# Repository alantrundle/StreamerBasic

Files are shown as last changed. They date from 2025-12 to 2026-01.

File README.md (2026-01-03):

# ESP32 Audio Streaming & Playback Platform

An all-in-one **ESP32-based audio platform** providing HTTP streaming, on-device decoding, and multiple audio outputs with a full graphical UI.  
Designed for **ESP32-WROVER (8MB PSRAM)** and intended for use with a custom PCB (v1.1) or off-the-shelf modules.

---

## 📸 PCB – Prototype (v1.1)

<p align="center">
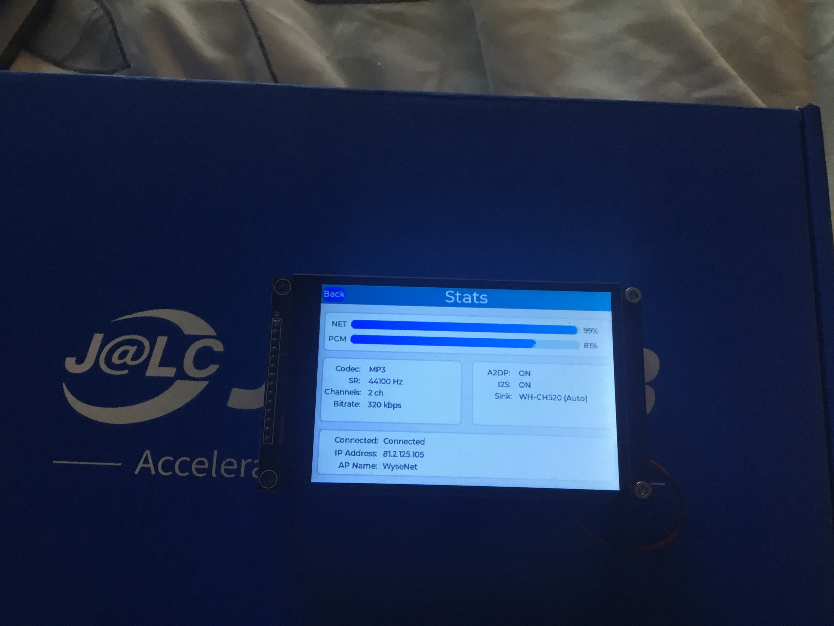
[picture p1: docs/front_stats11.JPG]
  
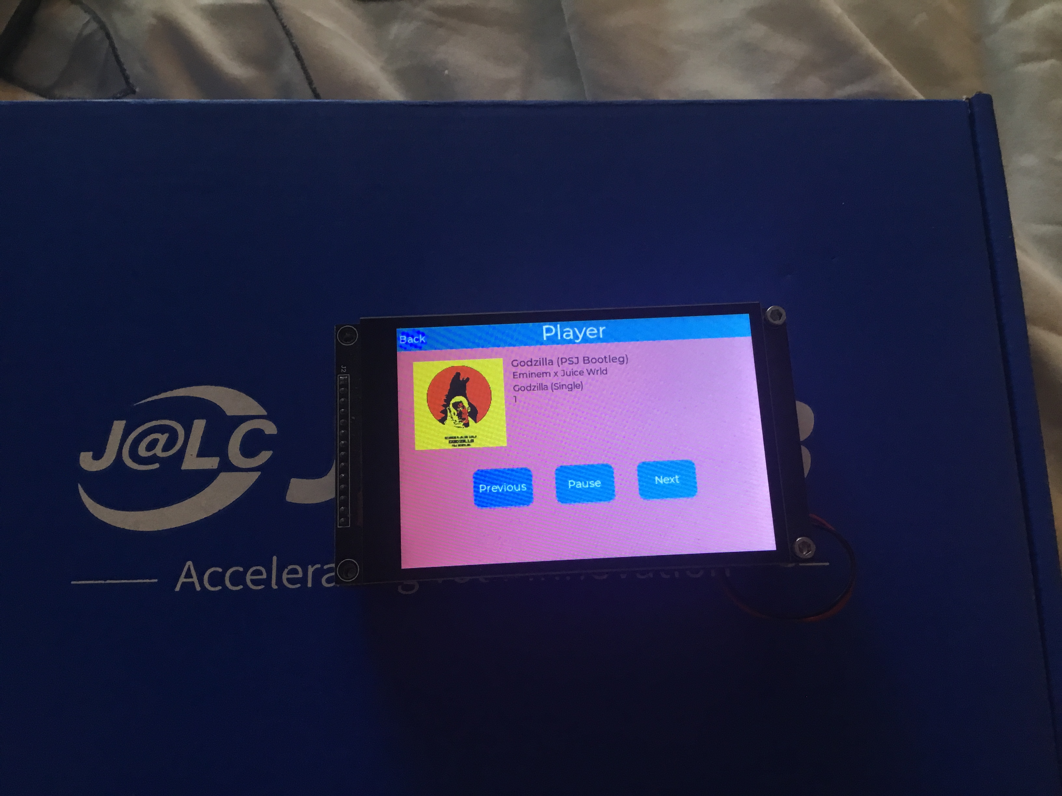
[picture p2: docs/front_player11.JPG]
  
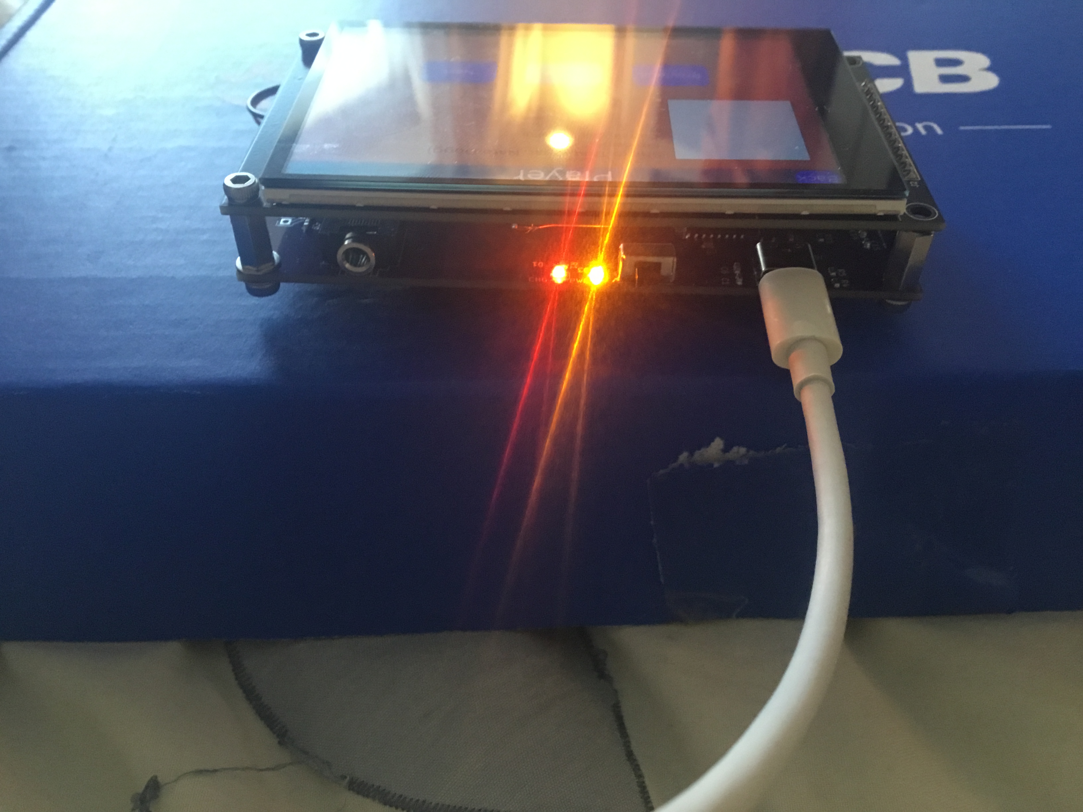
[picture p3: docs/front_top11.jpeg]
  
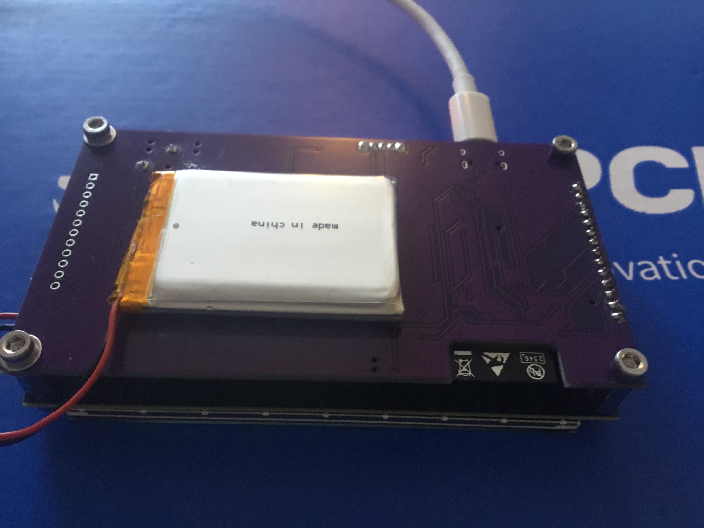
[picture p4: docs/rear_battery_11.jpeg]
  
</p>

**Left → Right:**  
Front view with LVGL UI • Angled top view • Rear view with Li-Po battery fitted

> ⚠️ **ESP32-WROVER with 8MB PSRAM is mandatory**  
> Bluetooth Classic (A2DP) and LVGL require PSRAM for stability.

---

## ✨ Key Features

- **Automatic MP3 & AAC codec detection** (header-level)
- **ID3v2 tag parsing** (title, artist, album & JPEG Album Art)
- **Bluetooth A2DP output**
  - Line-out & A2DP sinks supported
  - Automatic reconnect logic
- **I2S audio output**
  - Developed using PCM5102 DAC
- **Dual-reader PCM ring buffer**
  - Independent A2DP & I2S consumption
- **LVGL graphical UI**
  - Touch support
  - ST7796 demo included
- **Transport controls**
  - Play / Pause / Stop
  - Next / Previous track

---

## 🧠 Architecture Overview

- HTTP audio streaming
- On-device MP3 / AAC decoding
- Shared PCM buffer with independent read pointers
- Parallel output to:
  - Bluetooth A2DP
  - I2S DAC
- LVGL UI running primarily from PSRAM
- Designed around **FreeRTOS task separation** and buffer hysteresis

---

## ⚠️ Known Issues & Limitations

- **LVGL + Bluetooth + Wi-Fi are extremely DRAM-heavy**
  - LVGL buffers must reside mostly in PSRAM
  - Moving `lvbuf1` to DRAM can crash Wi-Fi + BT
- **Dual buffering in PSRAM is slow**
  - Trade-off required for system stability
- **Wi-Fi coexistence instability**
  - Occasional crashes under heavy load
- **ESP-IDF versions**
  - Rolled back to **ESP32 core v6.4.0** for stability
  - Newer versions attempt BT sleep → A2DP instability
- **Bluetooth**
  - Rare crashes due to DRAM exhaustion
  - Actively under investigation

---

## 🧪 Current Testing Status

- LVGL running partially in DRAM  
  - Single-buffer, 4-line configuration
- **24-hour soak test** currently in progress
- PCB **v1.1 production** underway

---

## 🛠 To-Do

- Plex Media Server integration
- General bug fixes & cleanup
- Ogg Vorbis support
- Improved AAC decoding
- LVGL dual buffering in DRAM (if feasible)

---

## ✅ Pros

- Stable during extended playback
- Robust codec detection
- Clean separation of decode and output paths
- Scales well with PSRAM availability

---

## 📦 Recommended Development Kit (Without PCB)

### ESP32 Module
**ESP32-WROVER (8MB PSRAM + TF Card)**
- https://www.aliexpress.com/item/32879370278.html

### Display
**4″ TFT Capacitive Touch Display**  
(Required for PCB v1.1 – LVGL)
- https://www.aliexpress.com/item/1005006698127763.html

### Audio DAC
**PCM5102 I2S DAC**
- Stereo RCA + headphone/line-out
- https://www.aliexpress.com/item/1005005352684938.html

---

## 📄 License

**Project status:** Active Development  

**License:**  
Free for **personal, educational, and hobbyist use**.

**Commercial use is not permitted without explicit written permission from the author.**  
This includes (but is not limited to) use in commercial products, services, or redistributed hardware.

If you wish to use this project commercially, please contact the author via GitHub.

---

## 🙌 Acknowledgements

- ESP32 Arduino Core
- LVGL Graphics Library
- Helix Audio Codecs

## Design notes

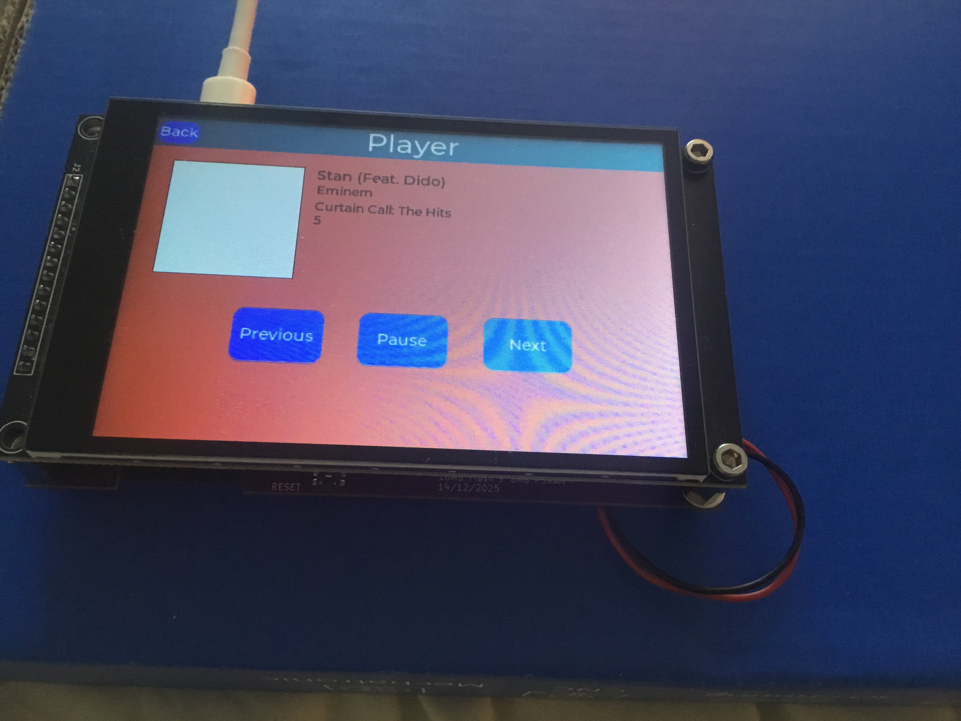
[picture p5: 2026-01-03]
docs/front11.jpeg

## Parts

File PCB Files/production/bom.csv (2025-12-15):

Designator | Footprint | Quantity | Value | LCSC Part #
C1, C15, C18, C19, C2, C23, C25, C26, C5, C7, C9 | 0603 | 11 | 100nF | C14663
C14, C20, C22, C3, C4, C6, C8 | 0603 | 7 | 10uF | C19702
C16, C17 | 0603 | 2 | 2.2nF | C1604
C21, C24 | 0603 | 2 | 2.2uF | C23630
D1 | 0805 | 1 | Charge | C84256
D2 | D_SOD-123 | 1 | MBR0520 | C8598
D3 | 0805 | 1 | LED | C2296
H1, H2, H3, H4 | MountingHole_3.2mm_M3_ISO14580 | 4 | MountingHole
J2 | JST_ZH_S2B-ZR-SM4A-TF_1x02-1MP_P1.50mm_Horizontal | 1 | Lipo 1S
J3 | PinSocket_1x14_P2.54mm_Vertical | 1 | Display
J4 | Jack_3.5mm_CUI_SJ1-3523N_Horizontal | 1 | AudioJack3 | C20182914
J5 | PinSocket_1x12_P2.54mm_Vertical | 1 | expansion
J6 | USB_C_Receptacle_HRO_TYPE-C-31-M-12 | 1 | USB_C_Receptacle_USB2.0_14P | C165948
Q1, Q2 | SOT-23 | 2 | AO3400A | C20917
Q3 | SOT-23 | 1 | AO3401A | C15127
R1, R3 | 0603 | 2 | 1k | C21190
R10 | 0603 | 1 | 220R | C22962
R11, R8 | 0603 | 2 | 10K | C25804
R2 | 0603 | 1 | 2.2k | C4190
R4, R5 | 0603 | 2 | 5k1 | C23186
R6, R7 | 0603 | 2 | 470R | C23179
R9 | 0603 | 1 | 100K | C25803
SW1 | SW_Slide_SPDT_Angled_CK_OS102011MA1Q | 1 | SW_SPST | C226259
SW2 | SW_SPST_EVQP7C | 1 | RESET | C388883
U1 | ESP32-WROVER-E | 1 | ESP32-WROVER-E | C701342
U2 | SOIC-16_3.9x9.9mm_P1.27mm | 1 | CH340C | C84681
U3 | SOT-23-5 | 1 | MCP73831-2-OT | C424093
U4 | SOT-23-5 | 1 | AP2112K-3.3 | C51118
U5 | TSSOP-20_4.4x6.5mm_P0.65mm | 1 | PCM5102A | C107671

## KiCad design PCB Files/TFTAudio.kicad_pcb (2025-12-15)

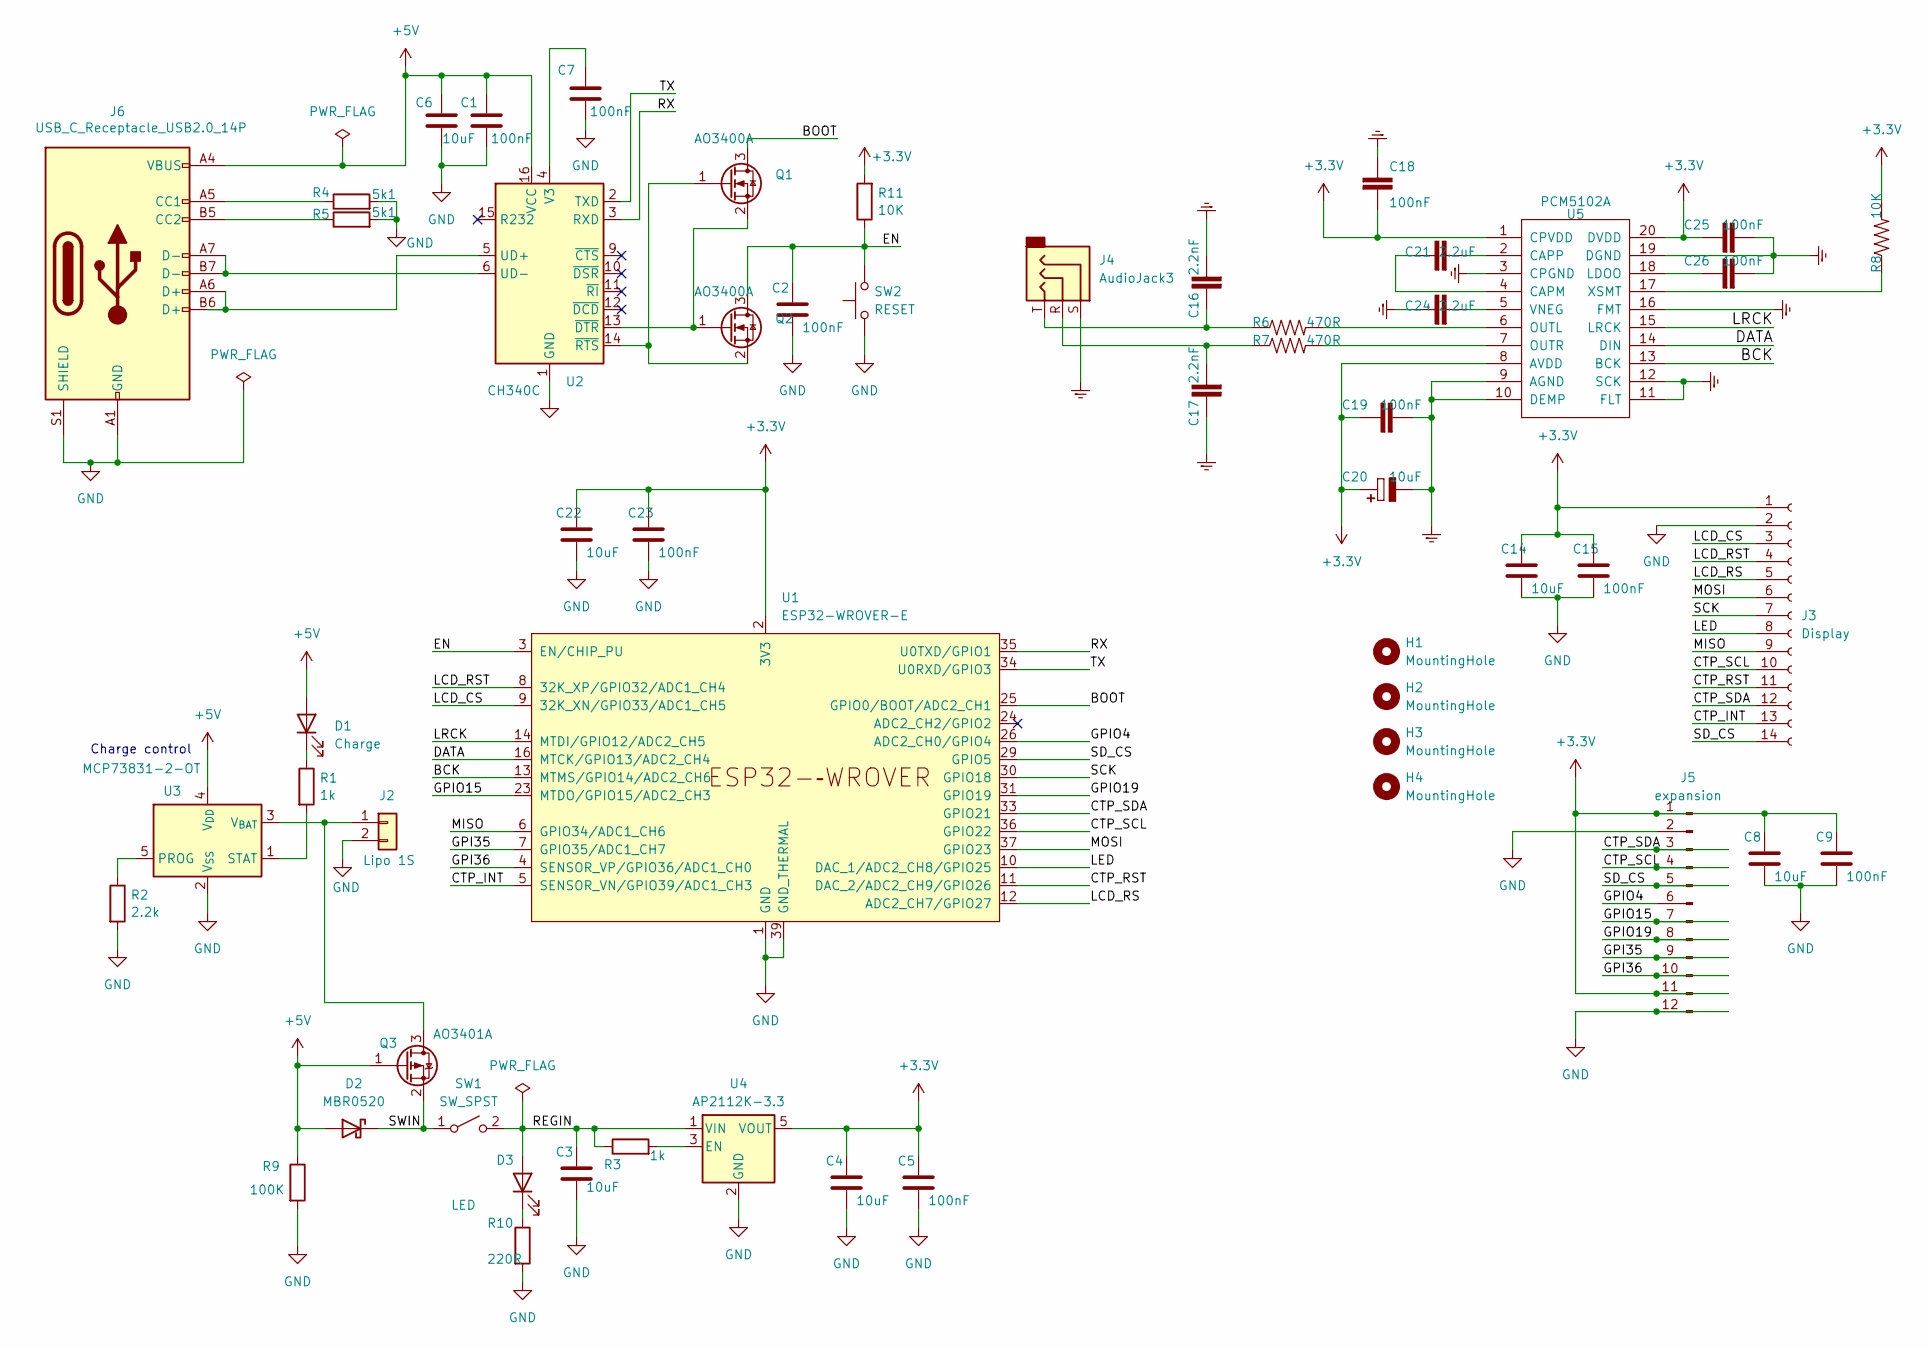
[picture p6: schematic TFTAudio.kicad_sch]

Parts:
C1, C2, C5, C7, C9, C15, C18, C19, C23, C25, C26: 100nF; C_0603_1608Metric; LCSC C14663
C3, C4, C6, C8, C14, C20, C22: 10uF; C_0603_1608Metric; LCSC C19702
C16, C17: 2.2nF; C_0603_1608Metric; LCSC C1604
C21, C24: 2.2uF; C_0603_1608Metric; LCSC C23630
D1: Charge; LED_0805_2012Metric; LCSC C84256
D2: MBR0520; D_SOD-123; LCSC C8598
D3: LED; LED_0805_2012Metric; LCSC C2296
H1, H2, H3, H4: MountingHole; MountingHole_3.2mm_M3_ISO14580
J2: Lipo 1S; JST_ZH_S2B-ZR-SM4A-TF_1x02-1MP_P1.50mm_Horizontal
J3: Display; PinSocket_1x14_P2.54mm_Vertical
J4: AudioJack3; Jack_3.5mm_CUI_SJ1-3523N_Horizontal; LCSC C20182914
J5: expansion; PinSocket_1x12_P2.54mm_Vertical
J6: USB_C_Receptacle_USB2.0_14P; USB_C_Receptacle_HRO_TYPE-C-31-M-12; LCSC C165948
Q1, Q2: AO3400A; SOT-23; LCSC C20917
Q3: AO3401A; Package_TO_SOT_SMD; LCSC C15127
R1, R3: 1k; R_0603_1608Metric; LCSC C21190
R2: 2.2k; R_0603_1608Metric; LCSC C4190
R4, R5: 5k1; R_0603_1608Metric; LCSC C23186
R6, R7: 470R; R_0603_1608Metric; LCSC C23179
R8, R11: 10K; R_0603_1608Metric; LCSC C25804
R9: 100K; R_0603_1608Metric; LCSC C25803
R10: 220R; R_0603_1608Metric; LCSC C22962
SW1: SW_SPST; SW_Slide_SPDT_Angled_CK_OS102011MA1Q; LCSC C226259
SW2: RESET; SW_SPST_EVQP7C; LCSC C388883
U1: ESP32-WROVER-E; LCSC C701342
U2: CH340C; SOIC-16_3.9x9.9mm_P1.27mm; LCSC C84681
U3: MCP73831-2-OT; SOT-23-5; LCSC C424093
U4: AP2112K-3.3; SOT-23-5; LCSC C51118
U5: PCM5102A; TSSOP-20_4.4x6.5mm_P0.65mm; LCSC C107671

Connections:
+3.3V: C4.1, C5.1, C8.1, C9.1, C14.1, C15.1, C18.2, C19.1, C20.1 (+), C22.1, C23.1, C25.1, J3.1, J5.1, J5.11, R8.2, R11.2, U1.2 (3V3), U4.5 (VOUT), U5.1 (CPVDD), U5.8 (AVDD), U5.20 (DVDD)
+5V: C1.1, C6.1, D1.2 (A), D2.2 (A), J6.A4 (VBUS), J6.A9 (VBUS), J6.B4 (VBUS), J6.B9 (VBUS), Q3.1 (G), R9.1, U2.16 (VCC), U3.4 (V_{DD})
/BCK: U1.13 (MTMS/GPIO14/ADC2_CH6), U5.13 (BCK)
/BOOT: Q1.3 (D), U1.25 (GPIO0/BOOT/ADC2_CH1)
/CTP_INT: J3.13, U1.5 (SENSOR_VN/GPIO39/ADC1_CH3)
/CTP_RST: J3.11, U1.11 (DAC_2/ADC2_CH9/GPIO26)
/CTP_SCL: J3.10, J5.4, U1.36 (GPIO22)
/CTP_SDA: J3.12, J5.3, U1.33 (GPIO21)
/DATA: U1.16 (MTCK/GPIO13/ADC2_CH4), U5.14 (DIN)
/EN: C2.1, Q2.3 (D), R11.1, SW2.2, U1.3 (EN/CHIP_PU)
/GPI35: J5.9, U1.7 (GPIO35/ADC1_CH7)
/GPI36: J5.10, U1.4 (SENSOR_VP/GPIO36/ADC1_CH0)
/GPIO4: J5.6, U1.26 (ADC2_CH0/GPIO4)
/GPIO15: J5.7, U1.23 (MTDO/GPIO15/ADC2_CH3)
/GPIO19: J5.8, U1.31 (GPIO19)
/LCD_CS: J3.3, U1.9 (32K_XN/GPIO33/ADC1_CH5)
/LCD_RS: J3.5, U1.12 (ADC2_CH7/GPIO27)
/LCD_RST: J3.4, U1.8 (32K_XP/GPIO32/ADC1_CH4)
/LED: J3.8, U1.10 (DAC_1/ADC2_CH8/GPIO25)
/LRCK: U1.14 (MTDI/GPIO12/ADC2_CH5), U5.15 (LRCK)
/MISO: J3.9, U1.6 (GPIO34/ADC1_CH6)
/MOSI: J3.6, U1.37 (GPIO23)
/REGIN: C3.1, D3.2 (A), R3.1, SW1.2 (B), U4.1 (VIN)
/RX: U1.35 (U0TXD/GPIO1), U2.3 (RXD)
/SCK: J3.7, U1.30 (GPIO18)
/SD_CS: J3.14, J5.5, U1.29 (GPIO5)
/SWIN: D2.1 (K), Q3.2 (S), SW1.1 (A)
/TX: U1.34 (U0RXD/GPIO3), U2.2 (TXD)
GND: C1.2, C2.2, C3.2, C4.2, C5.2, C6.2, C7.2, C8.2, C9.2, C14.2, C15.2, C16.2, C17.1, C18.1, C19.2, C20.2 (-), C22.2, C23.2, C24.1, C25.2, C26.2, J2.2, J3.2, J4.S, J5.2, J5.12, J6.A1 (GND), J6.A12 (GND), J6.B1 (GND), J6.B12 (GND), J6.S1 (SHIELD), R2.2, R4.2, R5.2, R9.2, R10.2, SW2.1, U1.1 (GND), U1.15 (GND), U1.38 (GND), U1.39 (GND_THERMAL), U2.1 (GND), U3.2 (V_{SS}), U4.2 (GND), U5.3 (CPGND), U5.9 (AGND), U5.10 (DEMP), U5.11 (FLT), U5.12 (SCK), U5.16 (FMT), U5.19 (DGND)
unnamed: C16.1, J4.T, R6.1
unnamed: C17.2, J4.R, R7.1
unnamed: D1.1 (K), R1.1
unnamed: D3.1 (K), R10.1
unnamed: J2.1, Q3.3 (D), U3.3 (V_{BAT})
unnamed: J6.A5 (CC1), R4.1
unnamed: J6.B5 (CC2), R5.1
unnamed: Q1.1 (G), Q2.2 (S), U2.14 (~RTS)
unnamed: Q1.2 (S), Q2.1 (G), U2.13 (~DTR)
unnamed: J6.A6 (D+), J6.B6 (D+), U2.5 (UD+)
unnamed: J6.A7 (D-), J6.B7 (D-), U2.6 (UD-)
unnamed: C7.1, U2.4 (V3)
unnamed: R2.1, U3.5 (PROG)
unnamed: R1.2, U3.1 (STAT)
unnamed: R3.2, U4.3 (EN)
unnamed: C21.1, U5.4 (CAPM)
unnamed: C21.2, U5.2 (CAPP)
unnamed: C26.1, U5.18 (LDOO)
unnamed: R6.2, U5.6 (OUTL)
unnamed: R7.2, U5.7 (OUTR)
unnamed: C24.2, U5.5 (VNEG)
unnamed: R8.1, U5.17 (XSMT)

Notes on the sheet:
Charge control

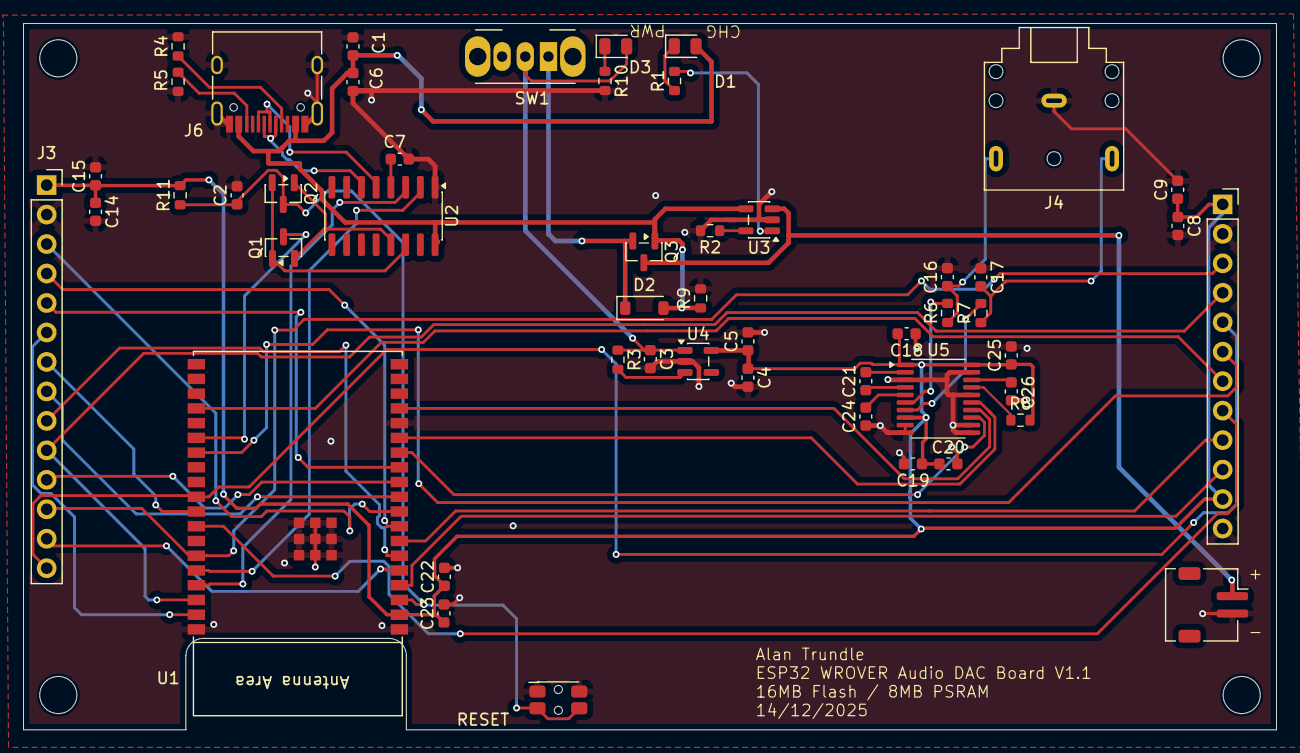
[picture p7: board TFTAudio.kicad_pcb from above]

Board: 2 copper layers, 108.0 x 60.9 mm, 55 parts (0 on the bottom side), 51 nets.

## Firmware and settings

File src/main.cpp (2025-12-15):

#include <Arduino.h>
#include <WiFi.h>
#include "esp_wifi.h"
#include "esp_system.h"

#include "Config.h"
#include "AudioCore.h"
#include "HttpStreamEngine.h"
#include "A2DPCore.h"

#include "LVGLCore.h"
#include "ui/ui.h"

#include "AudioPlayer.h"

#include "sdkconfig.h"

A2DPCore a2dp;


// ------------------------------------------------------------
// Wi-Fi helper
// ------------------------------------------------------------

static void connectWiFi() {
  Serial.printf("[WIFI] Connecting to %s\n", WIFI_SSID);

  WiFi.mode(WIFI_STA);
  WiFi.begin(WIFI_SSID, WIFI_PASS);

  uint32_t start = millis();
  while (WiFi.status() != WL_CONNECTED) {
    delay(250);
    Serial.print(".");
    if (millis() - start > 30000) {
      Serial.println("\n[WIFI] ❌ Connection timeout");
      return;
    }
  }



  Serial.printf("\n[WIFI] ✅ Connected, IP=%s\n",
                WiFi.localIP().toString().c_str());
}

#include <string.h>

void btScanCallback(int count,
                    const char* const* names,
                    const char* const* macs,
                    const int8_t* rssis)
{
    static bool connect = false;

    if (connect) return;

    for (int i = 0; i < count; i++) {

        if (!names[i]) continue;

        if (strcmp(names[i], "WH-CH520") == 0) {

            Serial.printf("Connecting to %s (%s, RSSI %d)\r\n",
                          names[i],
                          macs ? macs[i] : "??",
                          rssis ? rssis[i] : 0);

            a2dp.connect_by_index(i);
            connect = true;
            return;
        }
    }
}


void memUsage() {

size_t dma_free = heap_caps_get_largest_free_block(MALLOC_CAP_DMA | MALLOC_CAP_INTERNAL);
size_t int_free = heap_caps_get_free_size(MALLOC_CAP_INTERNAL);

Serial.printf("DMA largest free: %u bytes\n", dma_free);
Serial.printf("Internal free:   %u bytes\n", int_free);

}

static const char* wifi_ps_str(wifi_ps_type_t ps) {
  switch (ps) {
    case WIFI_PS_NONE:      return "NONE";
    case WIFI_PS_MIN_MODEM: return "MIN";
    case WIFI_PS_MAX_MODEM: return "MAX";
    default:               return "?";
  }
}


void health_log() {
  static uint32_t last = 0;
  uint32_t now = millis();

  if (now - last < 5UL * 60UL * 1000UL)
    return;
  last = now;

  // ---- Heap ----
  uint32_t int_free = heap_caps_get_free_size(MALLOC_CAP_INTERNAL);
  uint32_t int_min  = heap_caps_get_minimum_free_size(MALLOC_CAP_INTERNAL);

  uint32_t dma_free = heap_caps_get_largest_free_block(MALLOC_CAP_DMA);
  uint32_t dma_min  = heap_caps_get_minimum_free_size(MALLOC_CAP_DMA);

  // ---- WiFi info ----
  wifi_ps_type_t ps;
  esp_wifi_get_ps(&ps);

  wifi_ap_record_t ap{};
  bool ap_ok = (esp_wifi_sta_get_ap_info(&ap) == ESP_OK);

  // ---- Log ----
  Serial.printf(
    "[HEALTH] up=%lus "
    "Int=%u(min=%u) "
    "DMA=%u(min=%u) "
    "WiFi=%d PS=%s "
    "RSSI=%d Ch=%d "
    "BT=%d "
    "PCM=%d%% NET=%d%%\n",
    now / 1000,

    int_free, int_min,
    dma_free, dma_min,

    WiFi.status(),
    wifi_ps_str(ps),

    ap_ok ? ap.rssi : 0,
    ap_ok ? ap.primary : 0,

    a2dp.isConnected(),
    AudioCore::pcm_buffer_percent(),
    HttpStreamEngine::net_fill_percent()
  );
}


// ------------------------------------------------------------
// Arduino setup
// ------------------------------------------------------------

void setup() {
  Serial.begin(115200);
  delay(200);

  Serial.println("\n=== StreamerBasic ===");

  lvgl_init();

  // 1. Wi-Fi
  //esp_wifi_set_ps(WIFI_PS_NONE);
  
  // 2. Audio core (PCM, EQ, I2S, decoder tasks)
  if (!AudioCore::init()) {
    Serial.println("[MAIN] ❌ AudioCore init failed");
    while (true) delay(1000);
  }

  // 3. HTTP streamer (NET buffers + task)
  HttpStreamEngine::begin();

  a2dp.set_device_name("AT1053-Source");
  a2dp.set_autoreconnection(true);
  a2dp.set_pcm_callback(pcm_data_callback);
  a2dp.set_audiostate_callback(onA2DPAudioState);
  a2dp.set_connectionstate_callback(onA2DPConnectionState);
  a2dp.set_scan_callback(btScanCallback);
  a2dp.start();

  connectWiFi();

  //esp_bt_sleep_disable();

  // enable Player controls button now were up!
  lv_obj_clear_state(objects.start_btn, LV_STATE_DISABLED);

  memUsage();
}

// ------------------------------------------------------------
// Arduino loop (control plane only)
// ------------------------------------------------------------
static bool scan_started = false;

void loop() {

    a2dp.loop();
    AudioPlayer_Loop();

    health_log();

    //if (!a2dp.isConnected() && !a2dp.scan_blocked() && !scan_started) {
    //    a2dp.start_scan(10);
    //    scan_started = true;
    //}

    delay(100);

  }

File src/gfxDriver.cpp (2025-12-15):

#include <LovyanGFX.hpp>
#include "gfxDriver.h"
#include <Arduino.h>
#include <Wire.h>

/* ---- Global instance ---- */
LGFX_ST7796 display;

LGFX_ST7796::LGFX_ST7796() {
  /* ---- SPI bus ---- */
  {
    auto cfg = _bus.config();
    cfg.spi_host    = SPI3_HOST;     // VSPI
    cfg.spi_mode    = 0;
    cfg.freq_write  = 80000000;      // 80 MHz
    cfg.freq_read   = 16000000;
    cfg.spi_3wire   = false;
    cfg.use_lock    = true;
    cfg.dma_channel = 1;
    cfg.pin_sclk    = TFT_SCLK;
    cfg.pin_mosi    = TFT_MOSI;
    cfg.pin_miso    = TFT_MISO;
    cfg.pin_dc      = TFT_DC;
    _bus.config(cfg);
    _panel.setBus(&_bus);
  }

  /* ---- Panel ---- */
  {
    auto cfg = _panel.config();
    cfg.pin_cs        = TFT_CS;
    cfg.pin_rst       = TFT_RST;
    cfg.pin_busy      = -1;
    cfg.panel_width   = 320;       // ST7796 is 320x480
    cfg.panel_height  = 480;
    cfg.memory_width  = 320;
    cfg.memory_height = 480;
    cfg.offset_x = 0;
    cfg.offset_y = 0;
    cfg.offset_rotation = 0;
    cfg.readable   = false;
    cfg.invert     = false;
    cfg.rgb_order  = false;
    cfg.dlen_16bit = false;
    cfg.bus_shared = false;
    _panel.config(cfg);
  }

  /* ---- Backlight ---- */
  {
    auto cfg = _light.config();
    cfg.pin_bl      = TFT_BL;
    cfg.invert      = false;
    cfg.freq        = 20000;
    cfg.pwm_channel = 7;
    _light.config(cfg);
    _panel.setLight(&_light);
  }

  /* ---- Touch (FT6336/FT5x06) ---- */
  {
    // I2C is handled by LovyanGFX driver; configure pins and timing.
    auto tc = _touch.config();
    tc.x_min      = 0;
    tc.y_min      = 0;
    tc.x_max      = 320;        // raw portrait range for ST7796 module
    tc.y_max      = 480;
    tc.i2c_port   = 0;          // I2C_NUM_0
    tc.i2c_addr   = TOUCH_ADDR; // 0x38
    tc.pin_sda    = TOUCH_SDA;
    tc.pin_scl    = TOUCH_SCL;
    tc.pin_int    = TOUCH_INT;  // your INT pin = 5
    tc.pin_rst    = TOUCH_RST;  // your RST pin = 4
    tc.freq       = 400000;
    _touch.config(tc);

    _panel.setTouch(&_touch);   // attach touch to the panel
  }

  setPanel(&_panel);
}

bool LGFX_ST7796::readTouch(uint16_t &x, uint16_t &y, bool &pressed) {
  int32_t ix = 0, iy = 0;
  if (this->getTouch(&ix, &iy)) {     // <- use LGFX_Device::getTouch(...)
    x = (uint16_t)ix;
    y = (uint16_t)iy;
    pressed = true;
    return true;
  }
  pressed = false;
  return false;
}

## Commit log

2025-12-15 Initial commit (clean reset)
    [TFTAudio.kicad_pcb, TFTAudio.kicad_sch, bom.csv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]
2025-12-15 Altered PCM buffer size for stability + fixed PCM draining issues - Audio Side
    [AudioCore.cpp]
2025-12-15 minor logic flow bug fixes
    [AudioCore.cpp]
2025-12-15 production - Stable V1.1 - headphones out of range fix
    [AudioCore.cpp]
2025-12-21 minor fixes - AC dropped packets [STABLE]
    [AudioCore.cpp, AudioPlayer.cpp]
2025-12-22 idv3 fixes - set packet size to 256 [STABLE]
    [AudioCore.cpp, AudioPlayer.cpp, HttpStreamEngine.cpp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]
